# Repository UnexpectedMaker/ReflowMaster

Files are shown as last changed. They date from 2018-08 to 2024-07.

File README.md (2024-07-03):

# ReflowMaster

ReflowMaster is my original open source toaster oven reflow controller that I used to sell on tindie:
https://www.tindie.com/products/13378/

### This project is not compatible with ReflowMasterPro

Reflow Master

It's custom hardware and custom code but all open source so if you want the challenge of making one yourself or you want to hack the code, go for it!

I have a live stream build of the board here if you want to see what's involved
https://www.youtube.com/watch?v=OGQ-GZZ90oE

# ReflowMaster Design Files

Included in this repository:
- EagleCAD schematics and Board layout files (Eagle 9.1) 
- Exported Gerber files (Gerber 274X)
- STL files for the 3D printed case
- Adrduino code

# Open Source License
The hardware design files are released as open source under the CERN license. Please review the license before using these files in your own projects to understand your obligations.

# STL files for 3D printing
I have included the STL files for the case and also the exhaust fan adapter I made for my specific toaster oven. 

**NOTE:** Do not print the exhaust fan in PLA, please use PET-G or ABS as PLA warps/melts at a low temp. Also DO NOT connect the 3D printed exhaust fan directly to the metal of teh oven, it will melt and ruin your oven. You will need to add some heat resistant insulator between the metal and the 3D print. 

# Which TFT?
The TFT I am using is a 2.4" SPI TFT using the ILI9341 Driver available via...

AliExpress
https://s.click.aliexpress.com/e/_DevvrLr

Ebay
https://rover.ebay.com/rover/1/705-53470-19255-0/1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

# SAMD21 Bootloader
If you build your own Reflow Master, you will need to use a SAMD21G18 that already has an Arduino bootloader on it *before* it is put on the board. If you need to add a bootloader, you'll need an ATMEL ICE and an adapter for the chip. The cheapest adapter you can get is my SAMD21G Mangler available here...
https://www.tindie.com/products/13379/

# Updating firmware & Adding profiles - for Version 2.0.0
You can flash your Reflow Master with the Arduino IDE using the code provided above.

If you wish to add or change any of the reflow profiles, you need to do so in the code and re-flash the changes to your Reflow Master.

The Reflow Master board works like an "Adafruit Feather M0" - so you'll need to have the Adafruit Cortex m0 hardware profiles installed as well as the regular Cortex m0 Arduino profiles.

Reflow Master

You can use the instructions here to install everything you need to get up and running in the Arduino IDE:
https://learn.adafruit.com/adafruit-feather-m0-basic-proto/setup

You will also need the following libraries from Library Manager
- One Button
- Adafruit_GFX
- Adafruit_ILI9341

Once you have everything you need, you can download the code from this repo and put it into the Arduino folder where your sketches are stored, load the sketch, select Adafruit Feather M0 from the boards list, plug in your RM and turn it on, and select the correct port from the ports list and flash.
   
The easiest way to put a new profile into the code is to change one of the existing profiles, by altering the values in it's class initialiser. Information of what each value is is available in the ReflowMasterProfile.h file:
https://github.com/UnexpectedMaker/ReflowMaster/blob/master/Code/Reflow_Master_v2/ReflowMasterProfile.h
   
Enjoy!

# Support Unexpected Maker

I love designing, making and releasing my projects as open source. I do it because I believe it’s important to share knowledge and give back to the community, like many have done before me. It helps us all learn and grow.

That said, a lot of time, effort and finances have gone into designing and releasing these files, so please consider supporting me by buying some of my products:

https://unexpectedmaker.com/shop

https://www.tindie.com/stores/seonr/

Or by becoming a Patron:

https://www.patreon.com/unexpectedmaker

# Join my discord server
https://discord.com/invite/xAHpApP

# Unexpected Maker
https://unexpectedmaker.com

http://youtube.com/unexpectedmaker

http://twitter.com/unexpectedmaker

https://www.facebook.com/unexpectedmaker/

https://www.instagram.com/unexpectedmaker/

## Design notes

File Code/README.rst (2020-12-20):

Reflow Master Arduino Code
==========================

In this repository you'll find the Reflow Master code for Arduino in 2 different versions:

Reflow Master V1 and Reflow Master V2

Reflow Master V2 HISTORY:
-------------------------

- 19/12/2020 v2.00  
                    - Initial release.
- 20/12/2020 v2.01  
                    - Increased max bake time to 3 hours
                    - Added long press for Bake Time & Temp adjustment to quickly change values, clamped at max, so it won't loop
                    - Forgot to hookup minBakeTemp, minBakeTime, maxBakeTemp, maxBakeTemp variables to buttons
                    - Oven was not turned off correctly after the bake ended
- 20/12/2020 v2.02
                    - Prevent going into the bake menu when there is a TC error
                    - Set FAN to Off by default in settings
                    - Fixed some incorrect comments 
                    - Made TC error more visible on menu screen

Reflow Master V1 HISTORY:
-------------------------

- 01/08/2018 v1.0   
                    - Initial release.
- 13/08/2018 v1.01  
                    - Settings UI button now change to show SELECT or CHANGE depending on what is selected
- 27/08/2018 v1.02  
                    - Added tangents to the curve for ESP32 support, Improved graph curves, fixed some UI glitches, made end graph time value be the end profile time
- 28/08/2018 v1.03  
                    - Added some graph smoothing
- 20/05/2019 v1.04  
                    - Increased max curve to support profiles up to 8mins
                    - Added fan on time after reflow for cooldown settings
                    - Added extra profile for Ju Feng Medium temp paste
- 09/07/2019 v1.05  
                    - Fixed some bugs, Thanks Tablatronix!
- 16/09/2019 v1.06  
                    - Fixed probe offset temp not changing in settings
- 02/07/2020 v1.07  
                    - Cleaned up some Fan control and tracking code
                    - Cleaned up some debug messages
- 13/07/2020 v1.08  
                    - Fixed bug in DEBUG mode

Open Source License
-------------------

These files are released as open source under the MIT license. Please review the license before using these files in your own projects to understand your obligations.

Support Unexpected Maker
------------------------

I love designing, making and releasing our projects as open source. I do it because I believe it’s important to share knowledge and give back to the community, like many have done before me. It helps us all learn and grow.

That said, a lot of time, effort and finances have gone into designing and releasing these files, so please consider supporting me and following me on social media

If you'd like to support me on my journey, please consider buying one of my products on tindie

https://www.tindie.com/stores/seonr/

or at
https://unexpectedmaker.com/shop

Or become a Patron:

https://www.patreon.com/unexpectedmaker

Unexpected Maker
===================
http://youtube.com/c/unexpectedmaker

http://twitter.com/unexpectedmaker

https://www.facebook.com/unexpectedmaker/

https://www.instagram.com/unexpectedmaker/

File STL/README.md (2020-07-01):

# ReflowMaster 3D files for the Case

Reflow Master is my open source toaster oven reflow controller that I also sell full assembled on tindie:
https://www.tindie.com/products/13378/

Reflow Master

It's custom hardware and custom code but all open source so if you want the challenge of making one yourself or you want to hack the code, go for it!

I have a live stream build of the board here if you want to see what's involved
https://www.youtube.com/watch?v=OGQ-GZZ90oE

# STL files for 3D printing

Included in this folder are 3 versions of the Reflow Master case.

Functionally, the Rev1 and Rev2 are the same, but the Rev2 has a nicer, more modern look, and locations for the power switch and nuts for the screws print better.

There is also a Rev2 5.08mm version of the case that is bigger than the other Rev2, and that is because I am now shipping the latest version of my Reflow Master with 5.08m screw terminals, which requires extra space inside to fit.

**NOTE:** Do not print the exhaust fan in PLA, please use PET-G or ABS as PLA warps/melts at a low temp. Also DO NOT connect the 3D printed exhaust fan directly to the metal of teh oven, it will melt and ruin your oven. You will need to add some heat resistant insulator between the metal and the 3D print. 

Enjoy!

# Back me on Patreon?
I love making and designing projects but sharing open source projects takes a lot of thought and time. I do it because I think it’s important to share knowledge and give back to the community like many have done before me.

If you find this project useful or want to see more open source projects like it, please consider backing me on Patreon to say thanks!



Or by buying one of my products on tindie:

https://www.tindie.com/stores/seonr/

Or by buying one of my TinyPICO products:

https://tinypico.com

# Unexpected Maker
http://youtube.com/c/unexpectedmaker

http://twitter.com/unexpectedmaker

https://www.facebook.com/unexpectedmaker/

https://www.instagram.com/unexpectedmaker/

https://www.tindie.com/stores/seonr/

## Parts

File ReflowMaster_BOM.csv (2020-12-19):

Qty | Value | Device | Package | Parts | Description | PROD_ID | SF_SKU | VALUE
1 |  | ATSAMD21G-A | TQFP-48 | SAMD21 | Atmel SAMD21G SMART ARM-Based Microcontroller | IC-13064
5 |  | HEADER | 1X02 | BUZZ, FAN, K-TYPE, RELAY, SWITCH | 0.1” Header
1 |  | HEADER | 1X04_NO_SILK | J1 | 0.1” Header | CONN-09696
1 |  | HEADER | 1X14_NO_SILK | TFT | 0.1” Header
1 |  | USB-B-MICRO-SMD | USB-B-MICRO-SMD | J2 | USB Type Micro-B Connector | CONN-11752
2 | 0.1uF | CAPACITOR | 0805 | C3, C7 | Ceramic Capacitors
1 | 100k | RESISTOR | 0805 | R1 | RESISTOR
4 | 10k | RESISTOR | 0805 | R4, R5, R6, R11 | RESISTOR
1 | 10nF | CAPACITOR | 0805 | C5 | Ceramic Capacitors
2 | 10uF | CAPACITOR | 0805 | C6, C8 | Ceramic Capacitors
2 | 12pF | CAPACITOR | 0805 | C2, C4 | Ceramic Capacitors
1 | 1K2 | RESISTOR | 0805 | R9 | RESISTOR
2 | 1uF | CAPACITOR | 0805 | C1, C14 | Ceramic Capacitors
2 | 2K | RESISTOR | 0805 | R3, R8 | RESISTOR
1 | 300R | RESISTOR | 0805 | R7 | RESISTOR
1 | 32.768 | XTAL-3.2X1.5 | XTAL3215 | X2 | SMT Crsytal
1 | 430k | RESISTOR | 0805 | R2 | RESISTOR
1 | 600mA/40V | TRANS_NPN-MMBT2222AL | SOT23-3 | Q1 | NPN transistor | TRANS-08049 |  | 600mA/40V
1 | AP2112K | VREG_SOT23-5 | SOT23-5 | LDO | SOT23-5 Fixed Voltage Regulators
1 | GENERIC-SOIC8 | GENERIC-SOIC8 | SO08-UNIVERSAL | MAX31855 | Generic narrow & wide SOIC8
1 | GR | LED | 0805 | 13 | LED
1 | MBR120 | DIODESOD-123 | SOD-123 | D1 | Diode
4 | SWITCH-SPST | SWITCH-SPST | TACTILE_SWITCH_PTH_RIGHT_ANGLE_KIT | B1, B2, B3, B4 | Momentary Switch (Pushbutton) - SPST | CONN-10672 | COM-10791
1 | RD | LED | 0805 | 1 | LED
1 | SPST_TACT-KMR2 | SPST_TACT-KMR2 | KMR2 | SW1 | SMT 6mm switch, EVQQ2 series
1 | YEL | LED | 0805 | 2 | LED

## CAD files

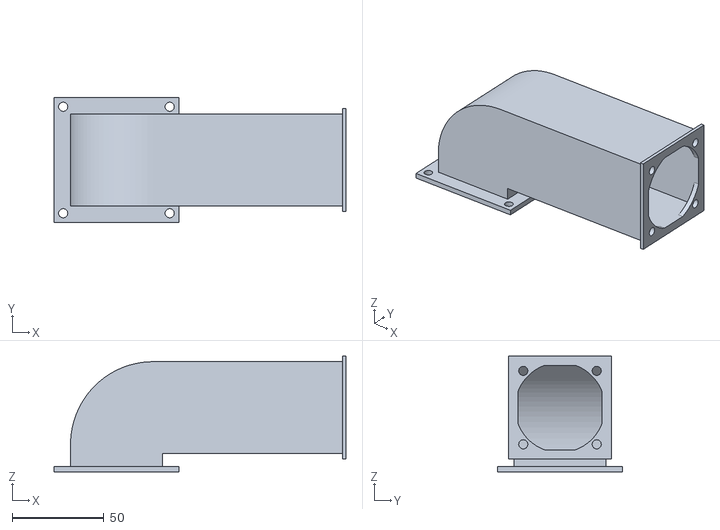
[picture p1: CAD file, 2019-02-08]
STL/Fan_Exhaust.stl
159.0 x 68.0 x 63.0

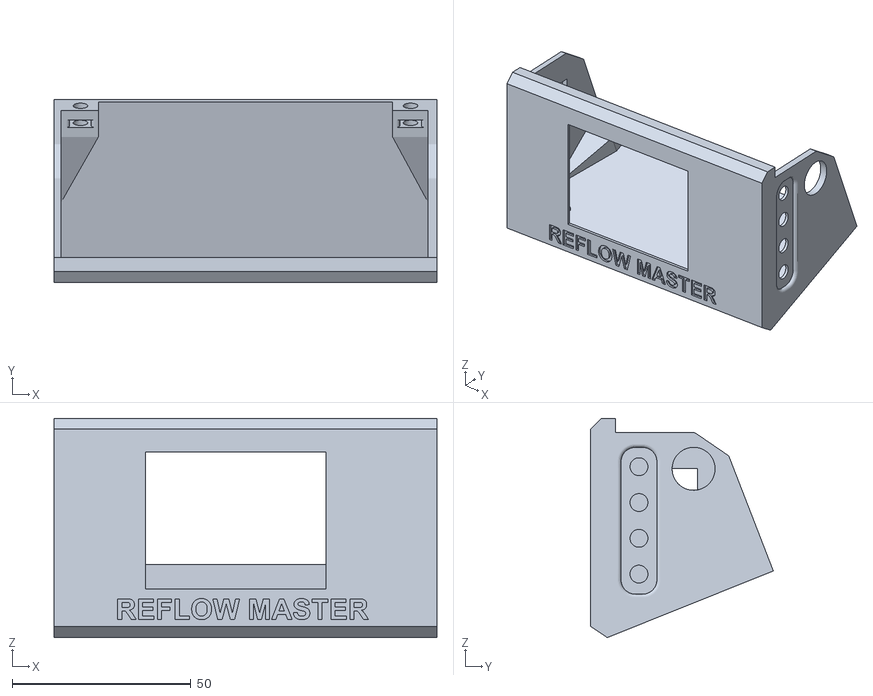
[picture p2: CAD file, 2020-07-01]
STL/Rev2 Case 2.54mm Screw Terminals/Reflow_Master_Front_V2.stl
107.0 x 51.0 x 61.2

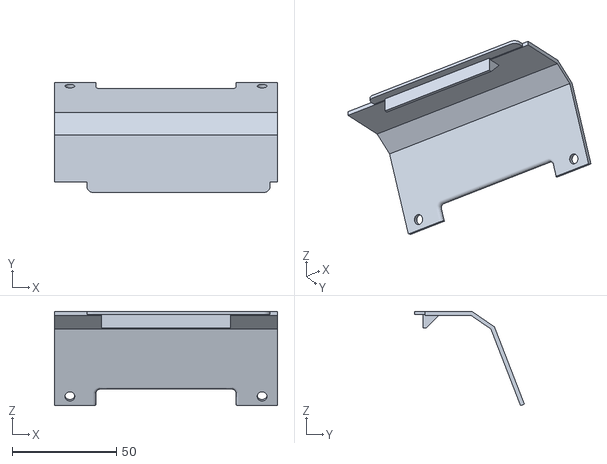
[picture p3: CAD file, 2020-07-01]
STL/Rev2 Case 5.08mm Screw Terminals/Reflow_Master_Back_V2_508mm.stl
107.0 x 52.7 x 45.3

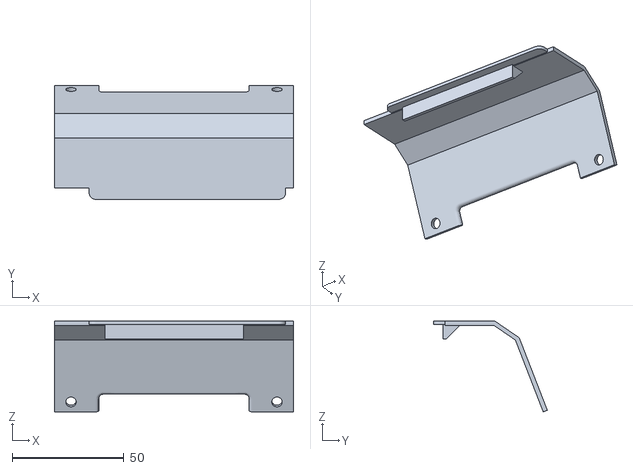
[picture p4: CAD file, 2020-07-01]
STL/Rev2 Case 2.54mm Screw Terminals/Reflow_Master_Back_V2.stl
107.0 x 50.9 x 40.6

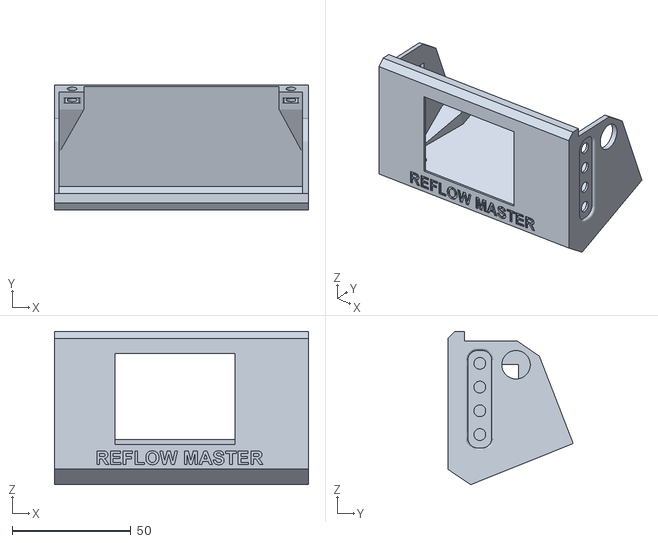
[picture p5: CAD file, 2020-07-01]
STL/Rev2 Case 5.08mm Screw Terminals/Reflow_Master_Front_V2_508mm.stl
107.0 x 52.8 x 64.6

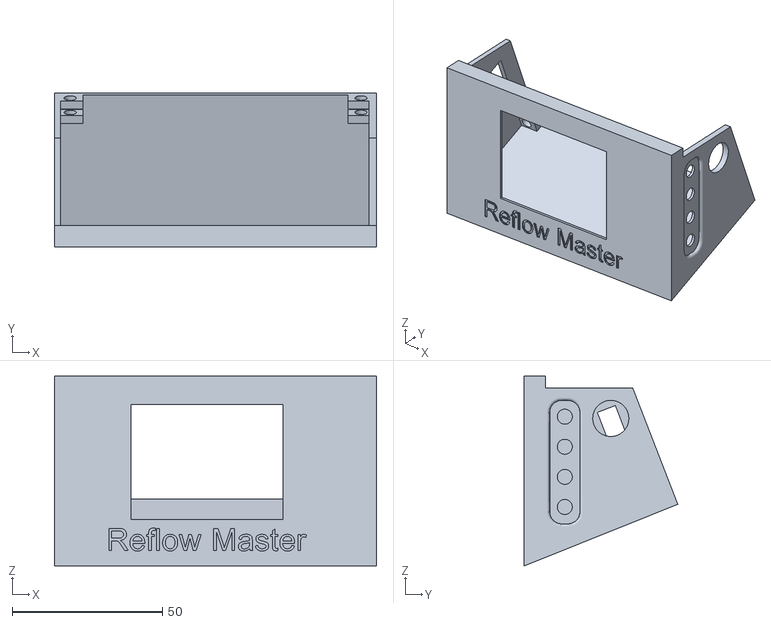
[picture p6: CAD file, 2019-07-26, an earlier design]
STL/Rev1 Case 2.54mm Screw Terminals/Case_Front_8.5mm_Header.stl
107.0 x 51.0 x 63.1

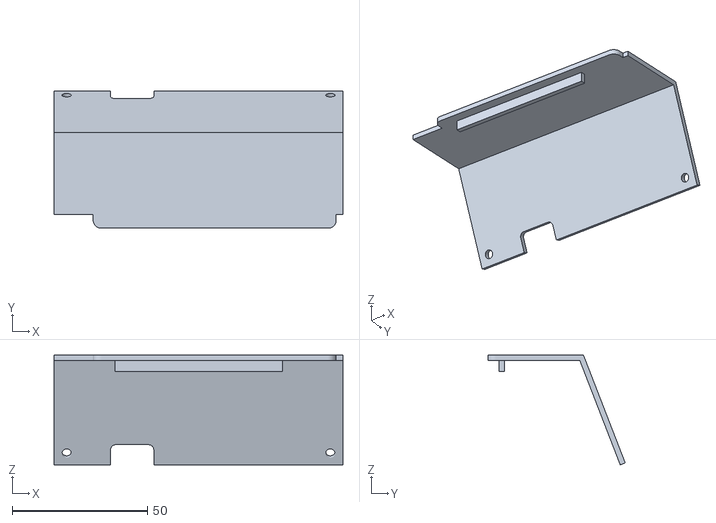
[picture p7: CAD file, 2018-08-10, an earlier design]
STL/Rev1 Case 2.54mm Screw Terminals/Case_Back.stl
107.0 x 50.9 x 40.6

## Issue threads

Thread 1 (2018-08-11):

BOM and Schematic PDF

DirtyEngineer, 2018-08-11:
Great project. Thanks for sharing it!

Might I suggest listing a BOM of the purchased parts?

 Affiliate links are always welcome as well.

Also I support your decision to add a "Buy Me A Coffee" link. So many times I've found and used an open source project and have no way of expressing my thanks to the person that put all the hard work into it.  I really wish GitHub had this integrated.

I've attached a PDF of the current schematic (Rev F) as I find this super handy when checking out a project.

[ReflowMaster_Rev_F.pdf](https://github.com/UnexpectedMaker/ReflowMaster/files/2280601/ReflowMaster_Rev_F.pdf)

UnexpectedMaker, 2018-08-11:
Hey Jon,

That’s quite funny… I had a schematic PDF and a BOM txt file sitting in my local repo uncommitted - had totally forgotten to push it… I am glad I did forget though, the BOM was slightly out of date and still included the SWD Debug header that is no longer on the board.

Thanks for the reminder to push it :-)

I’m not a fan of using a BOM that is linked to a supplier as everyone gets their parts from different places, and I often will source a set of parts for a board from 3-4 places based on costs and availability of parts, so I’m just including a TXT based BOM that people can load into their preferred suppliers sites.

I agree that GITHUB should offer a built in “donate” option for free repos, but it wasn’t too much effort to get this setup - no takers yet though ;)

Keep fighting the good fight!

DirtyEngineer, 2018-08-12:
Any chance you could include a little more detail as to specifically what screen is needed to work with this?

You would have had takers for your "donate" link if you hadn't threaten to refund donations during your live stream :)

UnexpectedMaker, 2018-08-12:
I've added links for AliExpress and eBay in the readme, and also added a bit about needing to install a bootloader on the SAMD21G before putting it on the board.

The people that were going to donate on my stream already support me by buying my products on tindie.. the donate button is for people that are not buying my products, but are instead using my open source files to make their own ;)

Closed 2018-08-11.

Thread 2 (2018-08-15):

hermite tangents not supplied

tablatronix, 2018-08-15:
I am surprised your environment doesn't crash because of this, esp32 does

```C++
  baseCurve.setPoints(CurrentGraph().reflowGraphX, CurrentGraph().reflowGraphY, CurrentGraph().len);
  baseCurve.setDegree( Hermite );
```

You specify Hermite, but provide no tangents to _m
`void setPoints( float x[], float y[], float m[], int numPoints );`

in spline, this causes exceptions on esp32, loadprohibited , since _m is unset

```C++
     // calc()
     // _m[i], _m[i+1]
      return hermite( ((x-_x[i]) / (_x[i+1]-_x[i])), _y[i], _y[i+1], _m[i], _m[i+1], _x[i], _x[i+1] );
```

Oddly , The spline lib doesn't seem to catch this or ensure that _m is set for hermite sets..

No idea what memory this accesses on samd, maybe its safer, shrug.

tablatronix, 2018-08-15:
my workaround is to just add tangents array to the reflowGraph class
and  fill it with 0s

```C++
float tangents[10];
...
for ( int i = 0; i < minLength; i++ )
tangents[i]     = 0;
```

UnexpectedMaker, 2018-08-15:
Hmm, interesting that it doesn't crash on the SAMD... I'll update the codebase anyway to include a defualt set of tangents. Thanks!

Closed 2018-08-15.

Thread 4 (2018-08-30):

SSR PWM potentially not fully on when set at 255

HowManyOliversAreThere, 2018-08-30:
According to the [Adafruit guide on Arduino sketches on SAMD21](https://learn.adafruit.com/adafruit-feather-m0-basic-proto/adapting-sketches-to-m0#analogwrite-pwm-range-7-7), performing an `AnalogWrite(255)` only sets the PWM to 255/256 rather than 255/255. As such, a special case is required to handle when it's at 255 and just digitally set the pin high. This is relevant to the `SetRelayFrequency` function

Might be worth investigating this, as it will improve ramp-up (marginally) and stop the toaster getting cut off and then slammed on again in periods where it should just be happily humming away. Unfortunately I don't have any hardware with which I could test this sorry, so might be a red herring if the info is wrong or the SAMD21 Arduino core has been changed.

UnexpectedMaker, 2018-09-01:
Hey Oliver
Thanks for this info. When I get some time I can hook a RM up to my scope and check out the results, but it's a simple thing to just add some code to do a digitalWrite(HIGH) and then PWM should be 100% duty cycle, though I assume it's not going to make any measurable change in oven temp/speed.
Seon

Closed 2020-12-21.

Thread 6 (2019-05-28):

Bom don’t contain certain part names only what package

NoSkillsToPayTheBillz, 2019-05-28:
I can’t seen to figure out what voltage regulators you are using? The diode is also just the package type. Also the crystal is the same just the package. Kinda confused about the 12.5 pf 0805s also since they aren’t able to be bought. I’ve asked and searched a few suppliers and have been told such a part isn’t made.

UnexpectedMaker, 2019-05-28:
I just updated the repo with missing component names and changed 12.5pF caps for the XTAL to 12pF.
Cheers :-)

NoSkillsToPayTheBillz, 2019-05-28:
Thanks that makes it some much easier only thing is what crystal is it that your using

UnexpectedMaker, 2019-05-28:
The Crystal I am using is discontinued, so you'l need to just source a 32.768 crystal with the size specs from the BOM and use that with matching caps. There are stacks to choose from.,

NoSkillsToPayTheBillz, 2019-05-28:
I ordered a NX3215SA so that should work match’s your specs. Thanks for your time I know your super busy with the Pico crowd source.

NoSkillsToPayTheBillz, 2019-05-28:
I ordered a NX3215SA so that should work match’s your specs. Thanks for your time I know your super busy with the Pico crowd source.

Closed 2019-05-28.

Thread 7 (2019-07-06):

abort immediate

tablatronix, 2019-07-06:
abort does not turn off heater immediately

- [ ] add `SetRelayFrequency(0);`
do not wait for return and loop

```C++
void AbortReflow()
{
   SetRelayFrequency(0); // relay off
  if ( state == 1 || state == 2 || state == 16 ) // if we are in warmup or reflow states
  {
```

- [x] moved in front of state checking, and always abort!, in case a bug causes a bad state etc.

UnexpectedMaker, 2019-07-07:
This has been improved in v1.04 that I am going to upload today, but the abort button should never be able to be pressed outside of those states, so not sure why you need SetRelayFrequency(0); outside the if statement.

It is inside the if statement in v1.04 :-)

tablatronix, 2019-07-07:
It was a safety thing, in case of a bug or loss of state , abort aborts always

UnexpectedMaker, 2019-07-07:
Right, but again, AbortReflow() is only ever called from a button press, and that press can only happen in those states...

```
    else if ( state == 1 || state == 2 || state == 16 )
    {
      AbortReflow();
    }
```

tablatronix, 2019-07-07:
I am always thinking about future abstraction less code coverage if abort gets called from a big red button or tc failure

Closed 2020-12-21.

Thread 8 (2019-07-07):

BUG? startFullBlast

tablatronix, 2019-07-07:
If I set startFullBlast true, ( I expected startup to be 100% for a bit )

Instead it goes 100% and stays 100%

I can't see whats wrong here

```C++
  // override for full blast at start
if ( set.startFullBlast && timeX < CurrentGraph().reflowGraphX[1] )
    duty = 256;`
```

seems like it should only override the first graph point or reflow level but it keeps going

Anyone have ideas, I am still trying to understand the `MatchTemp` function and timex graphing loop

UnexpectedMaker, 2019-07-07:
Hey mate - it sits at 100% for the entire start ramp, until it gets to the start of the pre-soak (reflowGraphX[1]) - this is really only designed for either high temp pastes to ensure you get to pre-soak as soon as it can, or for ovens that are just not powerful enough to get to any pre-soak in time.

I don't think anyone should be trying to use high temp paste in a toaster oven - bad bad bad!

It's pretty dangerous as it can overshoot the pre-soak start temp by a bit on a bad oven that can change temp fast enough.

tablatronix, 2019-07-07:
Hey thanks!
Yeah that is what I thought the code would do,

But it seems to do something else straight up

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

UnexpectedMaker, 2019-07-07:
Oh, you are getting past the wanted temp before pre-soak, and starting above start value - interesting. will fix that now in 1.0.4 - thanks for the use case - never encountered it before myself!

tablatronix, 2019-07-07:
I figured it was something like that, I have been working on some enhancements to pr and was always having an issue when I start with oven warmer than the profile start temp, I assume I need to do something to catch up the indexes to each other or something.

timeX seems to lag behind where it should be and is not synched to actual start temp, still reading the reflow code, I have almost all the rest figured out

UnexpectedMaker, 2019-07-07:
> timeX seems to lag behind where it should be and is not synched to actual start temp, still reading the reflow code, I have almost all the rest figured out

timeX doesn't lag behind, the system is designed to look ahead. it's never changing temp based on what it needs at it's current time... but at a look ahead time, as toaster ovens cant change temp that fast.

tablatronix, 2019-07-07:
Is timex an index of time? Of reflow slots 0-x?

UnexpectedMaker, 2019-07-07:
timeX is used to index into the curve of the current reflow graph, where CurrentGraph().reflowGraphX is time and CurrentGraph().reflowGraphY is temp. It's also the time count in seconds.

```
    if ( timeX < CurrentGraph().reflowGraphX[2] )
      wantedTemp = CurrentGraph().wantedCurve[ (int)timeX + set.lookAheadWarm ];
    else
      wantedTemp = CurrentGraph().wantedCurve[ (int)timeX + set.lookAhead ];
```
CurrentGraph().wantedCurve is an array of temps for every second of the profile, that is pre-processed when the profile is loaded on start or when the profile is changed.

tablatronix, 2019-07-07:
new code seems to work, I must misunderstand it, thanks

This is what threw me, timex was way greater and it was still doing full duty
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

tablatronix, 2019-07-07:
W00t

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

UnexpectedMaker, 2019-07-07:
Wicked! I have some thoughts on how to improve the visual look of the profile graph - but not had time to implement yet - I hate the smooth tangents on it right now, but messing with the tangent values isn't doing what I expect, so going to write my own curve code ;) one day....

UnexpectedMaker, 2019-07-07:
Is that running in your ESP32 port? or on SAMD?

tablatronix, 2019-07-07:
esp8266

UnexpectedMaker, 2019-07-07:
Wow, that's messy and marginally dangerous! ;)
I just pushed v1.05 - have fun!

Closed 2020-12-21.

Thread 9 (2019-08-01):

BUG? overshoots

tablatronix, 2019-08-01:
I think I found a bug, but I am hacking on my own fork and have not reproduced using upstream so was wondering if someone could confirm.

I noticed when I had sharp curves ( I am making some custom curves ) I was getting massive overshoots, 20-30C, and the heater would turn on randomly when way above wanted temp and even on cooldown, so I figured something might be wrong.

It looks like percent can be negative which causes duty to go above 0% and pulses the heater when it is not needed.

I added some sanity checking for perc and it seems to made a huge difference.
But if someone could check and test and make sure this is not going to break something.
change is below

`MatchTemp()`
```C++
    // prevent perc less than 1 and negative and greater than 100
    perc = constrain(wantedDiff - tempDiff,0,100);
    if(perc < 1) perc = 0;
```

**BAD log**
(ignore the T stamp, I am using a holding pattern)
```PHP
T: 70.00  Current: 125.30  Wanted: 105.00  T Diff: 0.00  W Diff: 0.00  Perc: 0.00  Delta: -20.30  Base: 0.00 -> SetRelayFrequency
RELAY Duty Cycle: write: 0.00 0.00% Using Power: 100%
Holding..

T: 70.00  Current: 125.68  Wanted: 105.00  T Diff: 0.37  W Diff: 0.00  Perc: 0.00  Delta: -20.68  Base: 0.00 -> SetRelayFrequency
RELAY Duty Cycle: write: 0.00 0.00% Using Power: 100%
Holding..

T: 70.00  Current: 125.60  Wanted: 105.00  T Diff: -0.08  W Diff: 0.00  Perc: 0.08  Delta: -20.60  Base: 0.00 -> SetRelayFrequency
RELAY Duty Cycle: write: 12.00 4.69% Using Power: 100% <------- HMMMM
Holding..

T: 70.00  Current: 125.39  Wanted: 105.00  T Diff: -0.21  W Diff: 0.00  Perc: 0.21  Delta: -20.39  Base: 0.00 -> SetRelayFrequency
RELAY Duty Cycle: write: 36.00 14.06% Using Power: 100%
```

tablatronix, 2019-08-01:
hmm, looks like there is something else going on actually.

disregard until I can look a bit more

```PHP
T: 70.00  Current: 131.70  Wanted: 105.00  T Diff: -0.37  W Diff: 0.00  Perc: 0.00  Delta: -26.70  Base: 0.00 -> SetRelayFrequency
RELAY Duty Cycle: write: 0.00 0.00% Using Power: 100%
Holding..
T: 70.00  Current: 130.65  Wanted: 105.00  T Diff: -1.05  W Diff: 0.00  Perc: 1.05  Delta: -25.65  Base: 0.00 -> SetRelayFrequency
RELAY Duty Cycle: write: 180.00 70.31% Using Power: 100%
Holding..

T: 70.00  Current: 130.85  Wanted: 105.00  T Diff: 0.20  W Diff: 0.00  Perc: 0.00  Delta: -25.85  Base: 0.00 -> SetRelayFrequency
RELAY Duty Cycle: write: 0.00 0.00% Using Power: 100%
Holding..
```

tablatronix, 2019-08-01:
I was able to deal with my overshoots by increasing lookaheadwarm and bumping power up a few thenths.

No idea what the pulsing the oven when its over wantedtemp is, something with the currentDetla (<mispelling) but I am not sure what that code does yet or what the variables you chose are

I am assuming some kind of swing 5, 15 and 172 and base 32, 128
Might look again later and see what the math is doing.

tablatronix, 2019-08-02:
I think alot of these issues are precision issues that do not present on the samd21, I am waiting to get one to be able to PR against master without breaking stuff or fighting other bugs.

Seems everything is a float and does not need to be, there are also alot of comparison warnings with -wall so might be any of those , I also have better luck sometimes by disabling lookahead, maybe it your oven is fast enough it harms more than helps

Closed 2020-12-21.

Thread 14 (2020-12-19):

Differential controller performance

DurandA, 2020-12-19:
Hi @UnexpectedMaker and thanks for your open-source projects and YouTube videos.

I am making a pretty similar project for a [hot plate](https://aliexpress.com/item/32888343657.html) where I replace the original controller board with a custom one. Since there is just space for a segment display and some buttons, reflow profile will be configured from a smartphone using BLE. The [hardware](https://easyeda.com/DurandA/reflow) is mostly final and I am now working on the [firmware](https://github.com/DurandA/reflow946) using ESP-IDF.

I stumbled upon your project and found that you use the same thermocouple chip (MAX31855) than me and I am wondering how did you settle on the current temperature controller. I started working on a PID controller but saw that that you are only using a differential input:
https://github.com/UnexpectedMaker/ReflowMaster/blob/29f8a3fb8e1a09a3da2df962912d4bd50d375017/Code/Reflow_Master_v2/Reflow_Master_v2.ino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

I did not try to tune the PID controller on the plate yet but was wondering how did you settle on a differential-only controller? Does the temperature closely match the chosen profile? I also saw some recommendations to rather use bang-bang (on-off) controllers for heaters due to the large inertia.

UnexpectedMaker, 2020-12-21:
I don't think PID is a good fit for reflow, so I implemented my own solution. It's not really differential control, and more a combo of a few techniques, that allows users to tune in a more understandable way.
But this really isn't a RM issue, so maybe my discord server is a better place to talk about it 👍
https://discord.com/invite/xAHpApP

DurandA, 2020-12-21:
Whoops, I meant proportional controller.

Sorry for opening an issue and thanks for the Discord link!

Closed 2020-12-21.

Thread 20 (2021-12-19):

Shortage of ATSAMD21G-A?

Bazmundi, 2021-12-19:
Currently looks like ATSAMD21G-A are hard to source.   How many of the SAM D21 family might be an optional drop-in replacement please?  Based on, I guess, why you opted for that chip.

https://au.mouser.com/c/?q=ATSAMD21G seem to have various SAM D21G variants.

UnexpectedMaker, 2021-12-19:
Reflow Master only supports the ATSAMD21G18A - in the QFP package.

Anything else will require you to modify the PCB design (if you go for a QFN package of the 21G18A) or require bootloader and code changes to work on a version with less Flash/SRAM.

UnexpectedMaker, 2021-12-19:
It's in stock at mouser... though not many.
https://au.mouser.com/ProductDetail/Microchip-Technology-Atmel/ATSAMD21G18A-AUT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

You only need 1 right?

Bazmundi, 2021-12-19:
Ta, I'll get me 10 but missed that in the search - too literal.

On Sun, Dec 19, 2021 at 5:39 PM Unexpected Maker ***@***.***>
wrote:

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

Bazmundi, 2021-12-19:
DOH, can't get the K-type  MAX31855K, have to wait (apparently)

On Sun, Dec 19, 2021 at 7:06 PM Asterion Daedalus <
***@***.***> wrote:

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

andygrillo, 2022-03-27:
ATSAMD21G18A in QFP seems to be hard to find with the main distributers. Given that I only need 1 for this project, and I don't have a programmer to load arduino, I thought to buy this board from aliexpress:

https://www.aliexpress.com/item/1005003445206496.html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

It appears from the fuzzy photo to have the ATSAMD21G18A in QFP package, and I can erasily upload the bootloader using the board. Once done I can hot gun the chip off the board and use it for the reflow oven PCB.

What do you think?

UnexpectedMaker, 2022-03-27:
Sure, using a doner chip from another board is fine, so long as you have the tools and skills to remove it and re-solder without killing it.

andygrillo, 2022-03-27:
great, ill do that then. I would assume a hot air gun should do the trick.

Closed 2023-03-29.

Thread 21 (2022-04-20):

Updated Board Files?

dmadison, 2022-04-20:
I ordered a board from you last year (thank you, by the way!) and it's labeled "2020-2". It looks like the EAGLE files in the repo are labeled "2018-3" and are missing the programing header.

Is there any chance you could update the board files in the repo to the latest version?

UnexpectedMaker, 2022-04-20:
Hi David, the files I'm keeping full open source are the original design files.
Is there a reason you need the newer files?

dmadison, 2022-04-20:
Thanks for the quick response, Seon.

I'm working on putting the controller, relay, and everything else into its own fully contained enclosure. As part of that I was planning to build an add-on button board so that the buttons face the same direction as the screen. I was hoping to use the design files as a position and wiring reference.

UnexpectedMaker, 2022-04-20:
The buttons are the same from a wiring point of view. Boards are identical in functionality and still run the same code. Spacing on buttons etc are also still the same. The board grew in the other direction just a little, so you should be able to reference the online version here for what you want to do.

dmadison, 2022-04-20:
Oh, I didn't realize it had grown in size as well. I'm planning on building a mounting bracket for the LCD / controller sandwich, so that might have an effect.

I don't want to make more work for you, but would you consider sharing a vector model of the board (DXF/SVG) with just the edge outline and drill points? That would be all I need for a CAD reference.

UnexpectedMaker, 2022-04-20:
This is the best I can do atm:
[ReflowMaster_Outline.pdf](https://github.com/UnexpectedMaker/ReflowMaster/files/8518353/ReflowMaster_Outline.pdf)

If you cant get what you need from this, I can look at something else on the weekend.

dmadison, 2022-04-20:
I can definitely make that work. Thanks!

dmadison, 2022-04-21:
In case it helps anyone, here's a cleaned up SVG version of the above file. I removed the vias and made the holes accurate to size (more or less):

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

Closed 2022-04-20.

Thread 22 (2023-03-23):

Which USB socket?

pastaclub, 2023-03-23:
Some BOM items are hard to identify, especially the Micro USB socket. What is the exact component used?

I tried two different components but they do not exactly fit the footprint. I noticed the two holes in the PCB, presumably for little bolts in the component (which would actually be very useful for manual pick and place).

Also, which exact MCU is used? The BOM just says ATSAMD21G-A, but there are dozens of variations of that chip in a 48pin package. Does it matter or can I pick any?

ns2gupta, 2023-03-29:
I think the design changed a lot since it was posted. I see that the new version uses ESP32.

@UnexpectedMaker, can you please share the updated schematic and board layout?

UnexpectedMaker, 2023-03-29:
> I think the design changed a lot since it was posted. I see that the new version uses ESP32.
>
> @UnexpectedMaker, can you please share the updated schematic and board layout?

Reflow Master hasn't changed design.

The ESP32 version is Reflow Master Pro, a different product and not open source.

UnexpectedMaker, 2023-03-29:
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

SAMD21G18A is the version you need. The specific USB connector is no longer available, nor can I find it listed, so you'll need to source a matching one, or alter the PCB to use a different connector and get the boards re-made.

pastaclub, 2023-04-01:
Thank you for the support!

Closed 2023-04-01.

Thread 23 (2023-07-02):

Ali Express Link is broken

laenzlinger, 2023-07-02:
Unfortunately the Link for buying the TFT on Ali Express is broken: AliExpress http://s.click.aliexpress.com/e/bQYyZYRe

Mike-Menci, 2023-07-02:
use any that has; /Google/  TFT display 2.4" SPI TFT using the ILI9341
or for example :
like this one :
https://www.amazon.de/-/en/HiLetgo-ILI9341-Display-Touch-Arduino/dp/B0814LK18M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

On Sun, 2 Jul 2023 at 21:45, Christof Laenzlinger ***@***.***>
wrote:

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

--
Mike

"--

**************************************************************************************************************
*This e-mail may be confidential and it may also be legally privileged. If
you are not the addressee you may not copy, forward, disclose or use any
part of it. If you have received this message in error, please delete it
and all copies from your system and notify the sender immediately by return
e-mail. Internet communications cannot be guaranteed to be timely, secure,
error or virus-free. The sender does not accept liability for any errors or
omissions. *
* SAVE THE NATURE - SAVE PAPER - THINK BEFORE YOU PRINT!  *"

Closed 2024-01-13.

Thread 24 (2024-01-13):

Reflow Master Pro ESP32 Code ¿?

jlabordaversa, 2024-01-13:
It is Reflow Master Pro ESP32 code available open source? I wanted to add some improvements to my oven.

Mike-Menci, 2024-01-13:
Yes Go ahead!

UnexpectedMaker, 2024-01-13:
No, reflow Master Pro is not open source.

UnexpectedMaker, 2024-01-13:
> It is Reflow Master Pro ESP32 code available open source? I wanted to add some improvements to my oven.

What functionality did you want added?

jaimelaborda, 2024-01-14:
Thank you very much for your reply.

I wanted to add PWM for fan outputs and also ideally I wanted to be able to turn the graphical interface 90 degrees so I can use it vertically as it would better fit my toaster oven. I am also thinking about changing the display to an smaller one.
But of course, if the project is not open source I cannot. I hoped that if the first version was open source this second one with the ESP32 would also be open source.

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

UnexpectedMaker, 2024-01-14:
@jaimelaborda AUX output is already PWM - You have the ability to set the FREQ and the % is the duty cycle.

If you can source a 2.2" ILI9341 screen that's 320x240, you can just switch the screens out, but that's not much smaller. Going smaller also drops the resolution and that's not compatible with the firmware.

Screen rotation or alternate resolution is not possible as the code is written fixed for 320x240 in the specific orientation the RMP ships in.

Closed 2025-01-08.

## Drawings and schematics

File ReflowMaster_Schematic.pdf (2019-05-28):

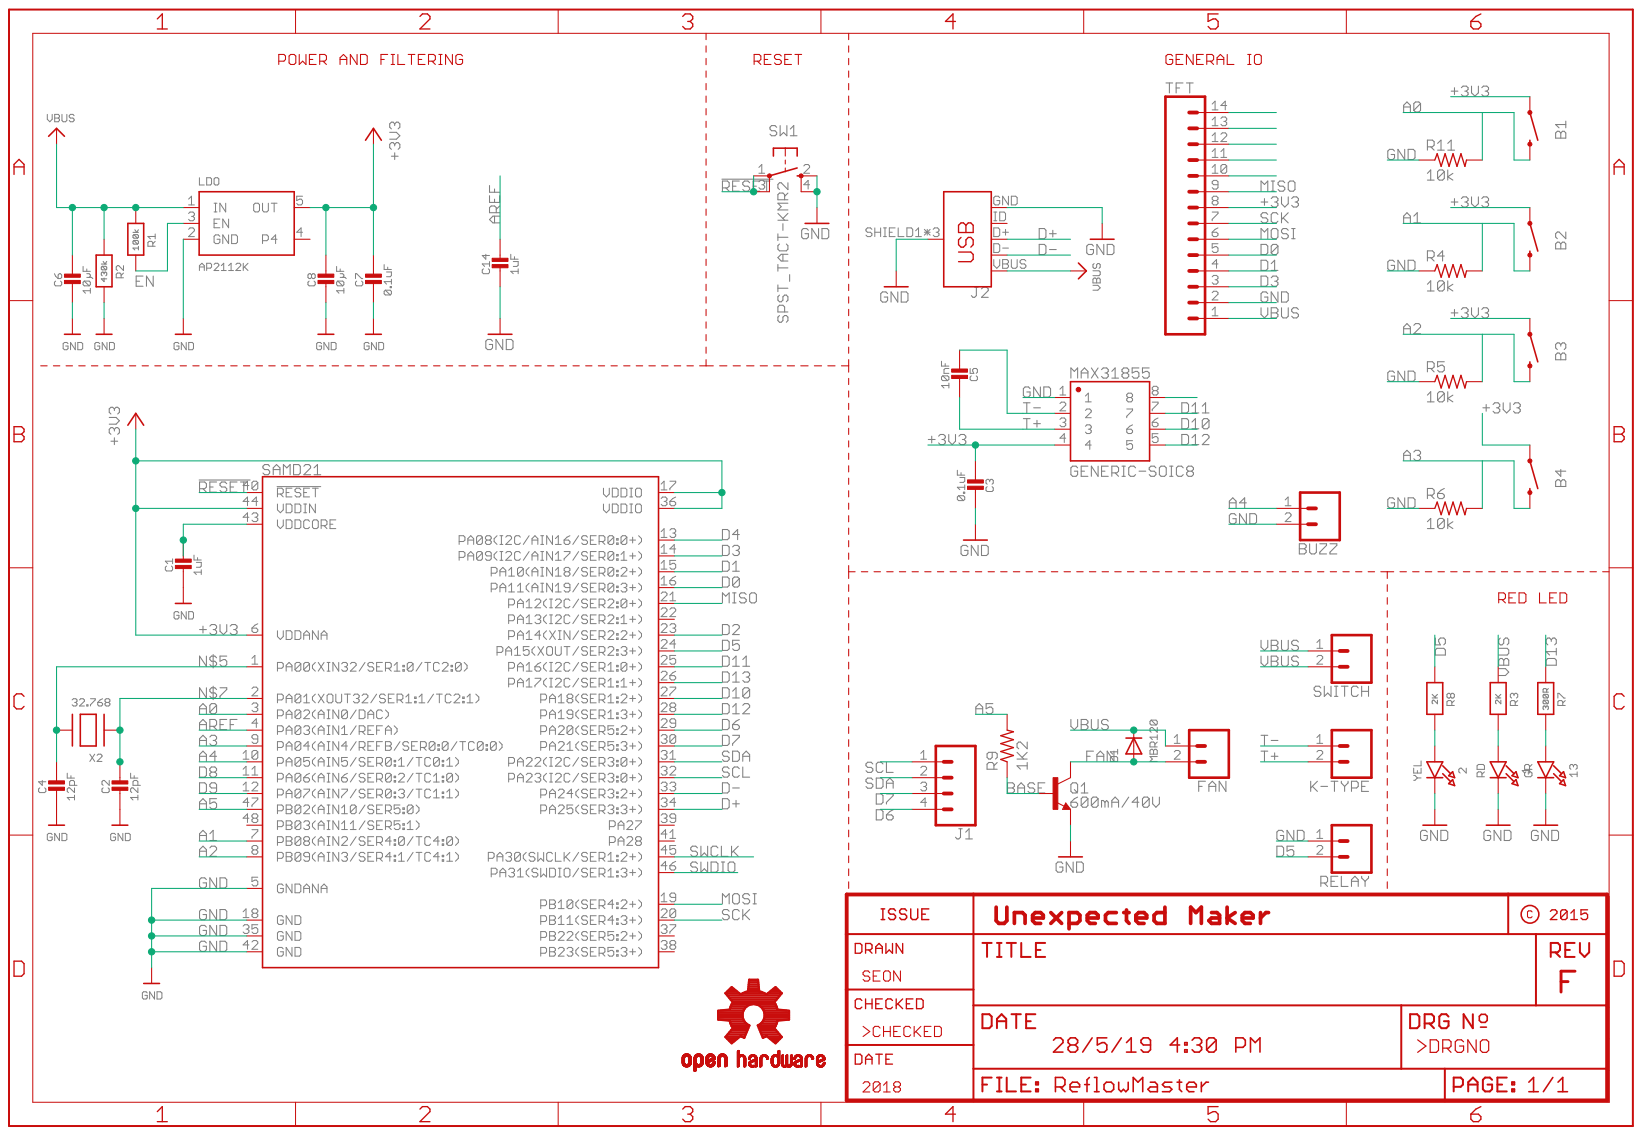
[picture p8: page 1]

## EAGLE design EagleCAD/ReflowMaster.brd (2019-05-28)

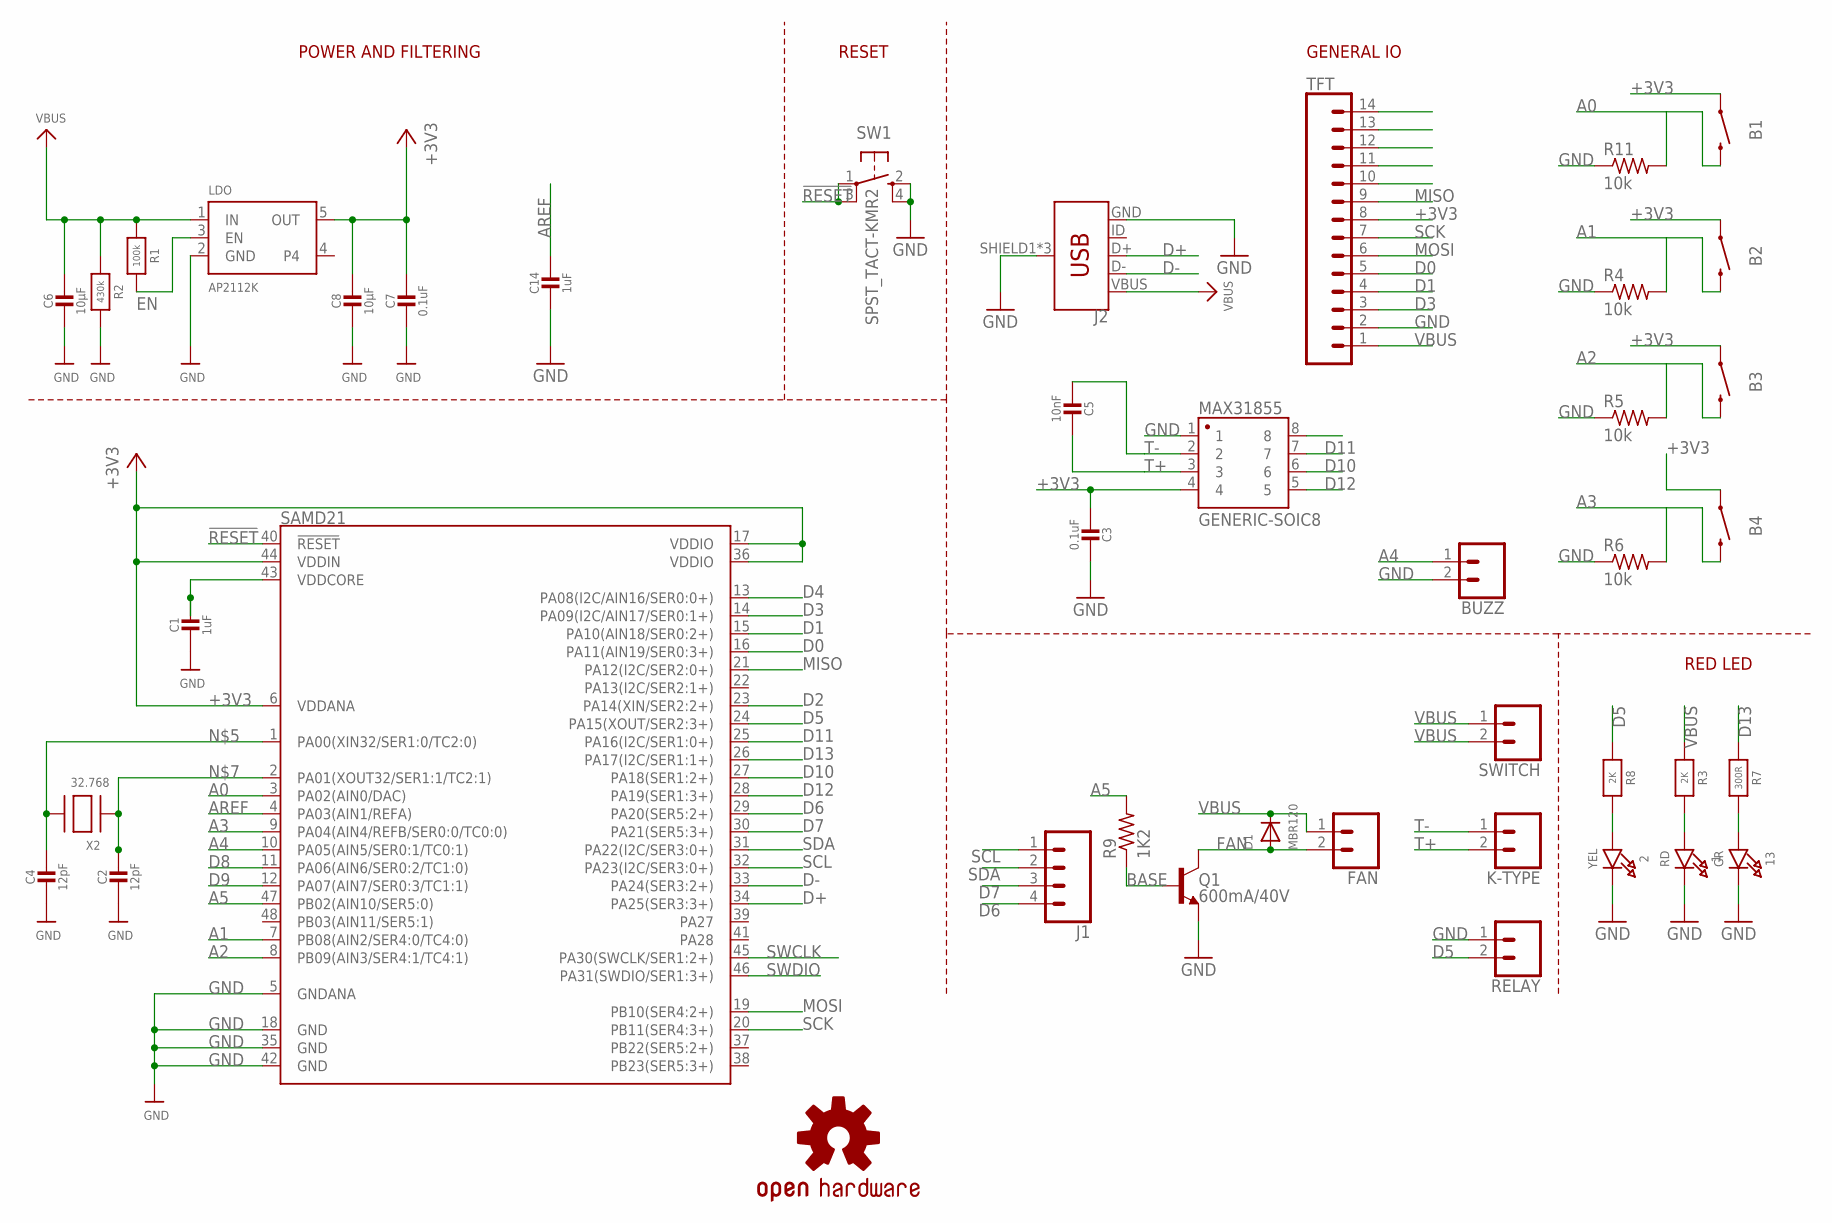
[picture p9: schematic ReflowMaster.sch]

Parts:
1: RD; CHIPLED_0805_NOOUTLINE
2: YEL; CHIPLED_0805_NOOUTLINE
13: GR; CHIPLED_0805_NOOUTLINE
B1, B2, B3, B4: MOMENTARY-SWITCH-SPST-PTH-RIGHT-ANGLE-KIT; TACTILE_SWITCH_PTH_RIGHT_ANGLE_KIT
BUZZ: CONN_02; 1X02
C1, C14: 1uF; 0805-NO
C2, C4: 12pF; 0805-NO
C3, C7: 0.1uF; 0805-NO
C5: 10nF; 0805-NO
C6, C8: 10µF; 0805-NO
D1: MBR120; SOD-123
FAN: CONN_02; 1X02
J1: CONN_041X04_NO_SILK; 1X04_NO_SILK
J2: USB_MICRO-B_FEMALE-SMT; USB-B-MICRO-SMD
K-TYPE: CONN_02; 1X02
LDO: AP2112K; SOT23-5
LOGO1: OSHW-LOGOS; OSHW-LOGO-S
MAX31855: GENERIC-SOIC8; SO08-UNIVERSAL
Q1: 600mA/40V; SOT23-3
R1: 100k; 0805-NO
R2: 430k; 0805-NO
R3, R8: 2K; 0805-NO
R4, R5, R6, R11: 10k; R0805
R7: 300R; 0805-NO
R9: 1K2; R0805
RELAY: CONN_02; 1X02
SAMD21: ATSAMD21G-A; TQFP-48
SW1: SPST_TACT-KMR2; KMR2
SWITCH: CONN_02; 1X02
TFT: CONN_14NO_SILK; 1X14_NO_SILK
X2: 32.768; XTAL3215

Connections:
!RESET: SAMD21.40 (!RESET!), SW1.1, SW1.3 (P1)
+3V3: B1.1, B2.1, B3.1, B4.1, C3.2, C7.1, C8.1, LDO.5 (OUT), MAX31855.4, SAMD21.6 (VDDANA), SAMD21.17 (VDDIO), SAMD21.36 (VDDIO), SAMD21.44 (VDDIN), TFT.8
A0: B1.2, R11.2, SAMD21.3 (PA02(AIN0/DAC))
A1: B2.2, R4.2, SAMD21.7 (PB08(AIN2/SER4:0/TC4:0))
A2: B3.2, R5.2, SAMD21.8 (PB09(AIN3/SER4:1/TC4:1))
A3: B4.2, R6.2, SAMD21.9 (PA04(AIN4/REFB/SER0:0/TC0:0))
A4: BUZZ.1, SAMD21.10 (PA05(AIN5/SER0:1/TC0:1))
A5: R9.2, SAMD21.47 (PB02(AIN10/SER5:0))
AREF: C14.1, SAMD21.4 (PA03(AIN1/REFA))
BASE: Q1.1 (B), R9.1
D0: SAMD21.16 (PA11(AIN19/SER0:3+)), TFT.5
D1: SAMD21.15 (PA10(AIN18/SER0:2+)), TFT.4
D2: SAMD21.23 (PA14(XIN/SER2:2+))
D3: SAMD21.14 (PA09(I2C/AIN17/SER0:1+)), TFT.3
D4: SAMD21.13 (PA08(I2C/AIN16/SER0:0+))
D5: R8.1, RELAY.2, SAMD21.24 (PA15(XOUT/SER2:3+))
D6: J1.4, SAMD21.29 (PA20(SER5:2+))
D7: J1.3, SAMD21.30 (PA21(SER5:3+))
D8: SAMD21.11 (PA06(AIN6/SER0:2/TC1:0))
D9: SAMD21.12 (PA07(AIN7/SER0:3/TC1:1))
D10: MAX31855.6, SAMD21.27 (PA18(SER1:2+))
D11: MAX31855.7, SAMD21.25 (PA16(I2C/SER1:0+))
D12: MAX31855.5, SAMD21.28 (PA19(SER1:3+))
D13: R7.1, SAMD21.26 (PA17(I2C/SER1:1+))
D+: J2.D+, SAMD21.34 (PA25(SER3:3+))
D-: J2.D-, SAMD21.33 (PA24(SER3:2+))
EN: LDO.3 (EN), R1.2
FAN: D1.A, FAN.2, Q1.3 (C)
GND: 1.C, 2.C, 13.C, BUZZ.2, C1.2, C2.2, C3.1, C4.2, C6.2, C7.2, C8.2, C14.2, J2.GND, J2.SHIELD1 (SHIELD), J2.SHIELD2 (SHIELD), J2.SHIELD3 (SHIELD), LDO.2 (GND), MAX31855.1, Q1.2 (E), R2.2, R4.1, R5.1, R6.1, R11.1, RELAY.1, SAMD21.5 (GNDANA), SAMD21.18 (GND), SAMD21.35 (GND), SAMD21.42 (GND), SW1.2 (S), SW1.4 (S1), TFT.2
MISO: SAMD21.21 (PA12(I2C/SER2:0+)), TFT.9
MOSI: SAMD21.19 (PB10(SER4:2+)), TFT.6
unnamed: 1.A, R3.2
unnamed: 13.A, R7.2
unnamed: 2.A, R8.2
unnamed: C4.1, SAMD21.1 (PA00(XIN32/SER1:0/TC2:0)), X2.P$2
unnamed: C2.1, SAMD21.2 (PA01(XOUT32/SER1:1/TC2:1)), X2.P$1
SCK: SAMD21.20 (PB11(SER4:3+)), TFT.7
SCL: J1.1, SAMD21.32 (PA23(I2C/SER3:0+))
SDA: J1.2, SAMD21.31 (PA22(I2C/SER3:0+))
SWCLK: SAMD21.45 (PA30(SWCLK/SER1:2+))
SWDIO: SAMD21.46 (PA31(SWDIO/SER1:3+))
T+: C5.1, K-TYPE.2, MAX31855.3
T-: C5.2, K-TYPE.1, MAX31855.2
VBUS: C6.1, D1.C, FAN.1, J2.VBUS, LDO.1 (IN), R1.1, R2.1, R3.1, SWITCH.1, SWITCH.2, TFT.1
VDDCORE: C1.1, SAMD21.43 (VDDCORE)

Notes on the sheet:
POWER AND FILTERING
RESET
GENERAL IO
RED LED

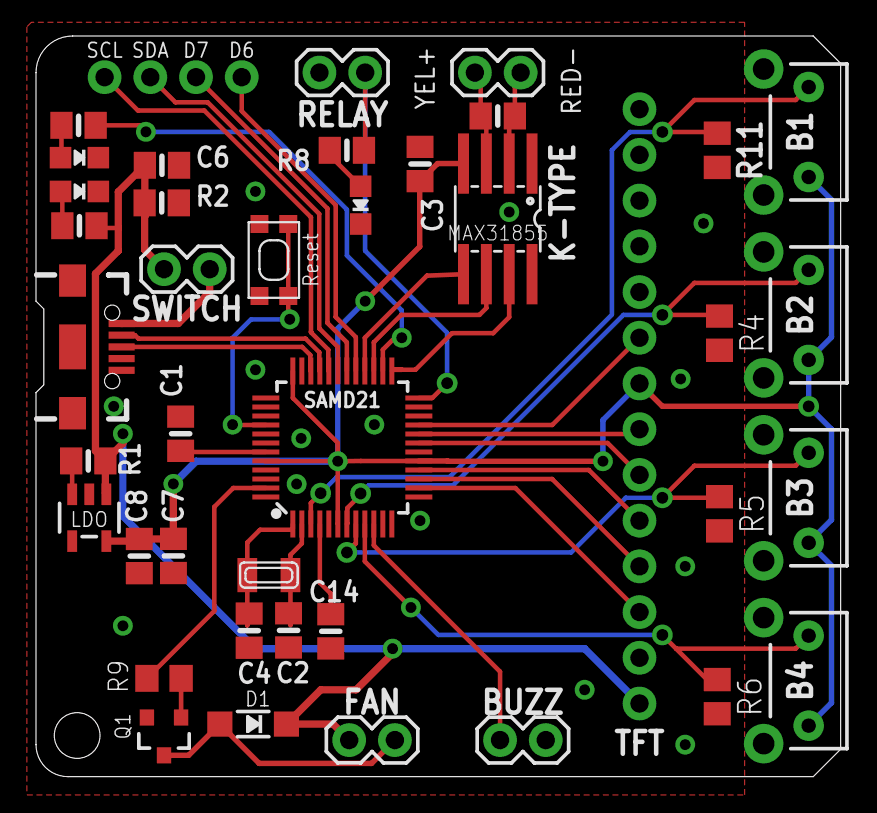
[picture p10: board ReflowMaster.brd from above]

Board: 2 copper layers, 44.7 x 41.1 mm, 42 parts (1 on the bottom side), 39 nets.

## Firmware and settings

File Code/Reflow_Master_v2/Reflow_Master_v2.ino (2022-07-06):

/*
  ---------------------------------------------------------------------------
  Reflow Master Control - v2.05 - 07/07/2022

  AUTHOR/LICENSE:
  Created by Seon Rozenblum - seon@unexpectedmaker.com
  Copyright 2016 License: GNU GPL v3 http://www.gnu.org/licenses/gpl-3.0.html

  LINKS:
  Project home: github.com/unexpectedmaker/reflowmaster
  Blog: unexpectedmaker.comYes, 

  PURPOSE:
  This controller is the software that runs on the Reflow Master toaster oven controller made by Unexpected Maker

  HISTORY:
  01/08/2018 v1.0   - Initial release.
  13/08/2018 v1.01  - Settings UI button now change to show SELECT or CHANGE depending on what is selected
  27/08/2018 v1.02  - Added tangents to the curve for ESP32 support, Improved graph curves, fixed some UI glitches, made end graph time value be the end profile time
  28/08/2018 v1.03  - Added some graph smoothing
  20/05/2019 v1.04  - Increased max curve to support profiles up to 8mins
                    - Added fan on time after reflow for cooldown settings
                    - Added extra profile for Ju Feng Medium temp paste
  07/09/2019 v1.05  - Fixed some bugs, Thanks Tablatronix!
  16/09/2019 v1.06  - Fixed probe offset temp not changing in settings
  02/07/2020 v1.07  - Cleaned up some Fan control and tracking code
                    - Cleaned up some debug messages
  13/07/2020 v1.08  - Fixed bug in DEBUG mode
  17/07/2020 v1.09  - Added TC error display in menu if an error is found
                    - Prevent starting reflow or oven check if there is a TC error
                    - Code refactor for easier reading? maybe?
  19/12/2020 v2.00  - Added baking mode
                    - Lots of code cleanup and simplification
                    - Included the more obscure libraries inside the sketch
  20/12/2020 v2.01  - Forgot to hookup minBakeTemp, minBakeTime, maxBakeTemp, maxBakeTemp variables to buttons
                    - Increased max bake time to 3 hours
                    - Added long press for Bake Time & Temp to quickly change values, clamped at max, so it won't loop
                    - Oven was not turned off correctly after the bake ended
  20/12/2020 v2.02  - Prevent going into the Bake menu when there is a thermocouple error
                    - Set FAN to Off by default
                    - Fixed some incorrect comments 
                    - Made TC error more visible
  21/12/2020 v2.02  - Fixed UI glitch in main menu with TC error display
  12/05/2021 v2.03  - Increased BAKE max Temperature to 150deg C
  31/10/2021 v2.04  - Some code cleanup and optimisations and merge of fixes from @dmadison
  07/07/2022 v2.05  - Fixed a compiler error with spline lib using latest Adafruit SAMD board definitions (>1.6.6)
  -----------------------------------------------------------------------------------------------------------------
*/

/*
   NOTE: This is a work in progress...
*/

#include <SPI.h>
#include "spline.h"
#include "Adafruit_GFX.h" // Add from Library Manager
#include "Adafruit_ILI9341.h" // Add from Library Manager
#include "MAX31855.h"
#include "OneButton.h" // Add from Library Manager
#include "ReflowMasterProfile.h"
#include "FlashStorage.h"

// used to obtain the size of an array of any type
#define ELEMENTS(x)   (sizeof(x) / sizeof(x[0]))

// used to show or hide serial debug output
#define DEBUG

// TFT SPI pins
#define TFT_DC 0
#define TFT_CS 3
#define TFT_RESET 1

// MAX 31855 Pins
#define MAXDO   11
#define MAXCS   10
#define MAXCLK  12

#define BUTTON0 A0 // menu buttons
#define BUTTON1 A1 // menu buttons
#define BUTTON2 A2 // menu buttons
#define BUTTON3 A3 // menu buttons

#define BUZZER A4  // buzzer
#define RELAY 5    // relay control
#define FAN A5     // fan control

// Just a bunch of re-defined colours
#define BLUE      0x001F
#define TEAL      0x0438
#define GREEN     0x07E0
#define CYAN      0x07FF
#define RED       0xF800
#define MAGENTA   0xF81F
#define YELLOW    0xFFE0
#define ORANGE    0xFC00
#define PINK      0xF81F
#define PURPLE    0x8010
#define GREY      0xC618
#define WHITE     0xFFFF
#define BLACK     0x0000
#define DKBLUE    0x000D
#define DKTEAL    0x020C
#define DKGREEN   0x03E0
#define DKCYAN    0x03EF
#define DKRED     0x6000
#define DKMAGENTA 0x8008
#define DKYELLOW  0x8400
#define DKORANGE  0x8200
#define DKPINK    0x9009
#define DKPURPLE  0x4010
#define DKGREY    0x4A49

// Save data struct
typedef struct {
  boolean valid = false;
  boolean useFan = false;
  int fanTimeAfterReflow = 60;
  byte paste = 0;
  float power = 1;
  int lookAhead = 6;
  int lookAheadWarm = 1;
  int tempOffset = 0;
  long bakeTime = 1200; // 20 mins
  float bakeTemp = 45; // Degrees C
  int bakeTempGap = 3; // Aim for the desired temp minus this value to compensate for overrun
  bool startFullBlast = false;
  bool beep = true;
} Settings;

// UI and runtime states
enum states {
  BOOT = 0,
  WARMUP = 1,
  REFLOW = 2,
  FINISHED = 3,
  MENU = 10,
  SETTINGS = 11,
  SETTINGS_PASTE = 12,
  SETTINGS_RESET = 13,
  OVENCHECK = 15,
  OVENCHECK_START = 16,
  BAKE_MENU = 20,
  BAKE = 21,
  BAKE_DONE = 22,
  ABORT = 99
} state;

const String ver = "2.05";
bool newSettings = false;

// TC variables
unsigned long nextTempRead;
unsigned long nextTempAvgRead;
int avgReadCount = 0;

unsigned long keepFanOnTime = 0;

double timeX = 0;
double tempOffset = 60;

// Bake variables
long currentBakeTime = 0; // Used to countdown the bake time
byte currentBakeTimeCounter = 0;
int lastTempDirection = 0;
long minBakeTime = 600; // 10 mins in seconds
long maxBakeTime = 10800; // 3 hours in seconds
float minBakeTemp = 45; // 45 Degrees C
float maxBakeTemp = 150; // 100 Degrees C

// Current index in the settings screen
int settings_pointer = 0;

// Initialise an array to hold 5 profiles
// Increase this array if you plan to add more
ReflowGraph solderPaste[5];
// Index into the current profile

int currentGraphIndex = 0;

// Calibration data - currently diabled in this version
int calibrationState = 0;
long calibrationSeconds = 0;
long calibrationStatsUp = 0;
long calibrationStatsDown = 300;
bool calibrationUpMatch = false;
bool calibrationDownMatch = false;
float calibrationDropVal = 0;
float calibrationRiseVal = 0;

// Runtime reflow variables
int tcError = 0;
bool tcWasError = false;
bool tcWasGood = true;
float currentDuty = 0;
float currentTemp = 0;
float cachedCurrentTemp = 0;
float currentTempAvg = 0;
float lastTemp = -1;
float currentDetla = 0;
unsigned int currentPlotColor = GREEN;
bool isCuttoff = false;
bool isFanOn = false;
float lastWantedTemp = -1;
int buzzerCount = 5;

// Graph Size for UI
int graphRangeMin_X = 0;
int graphRangeMin_Y = 30;
int graphRangeMax_X = -1;
int graphRangeMax_Y = 165;
int graphRangeStep_X = 30;
int graphRangeStep_Y = 15;

// Create a spline reference for converting profile values to a spline for the graph
Spline baseCurve;

// Initialise the TFT screen
Adafruit_ILI9341 tft = Adafruit_ILI9341(TFT_CS, TFT_DC, TFT_RESET);

// Initialise the MAX31855 IC for thermocouple tempterature reading
MAX31855 tc(MAXCLK, MAXCS, MAXDO);

// Initialise the buttons using OneButton library
OneButton button0(BUTTON0, false);
OneButton button1(BUTTON1, false);
OneButton button2(BUTTON2, false);
OneButton button3(BUTTON3, false);

// UI button positions and sizes
int buttonPosY[] = { 19, 74, 129, 184 };
int buttonHeight = 16;
int buttonWidth = 4;

// Initiliase a reference for the settings file that we store in flash storage
Settings set;
// Initialise flash storage
FlashStorage(flash_store, Settings);

// This is where we initialise each of the profiles that will get loaded into the Reflkow Master
void LoadPaste()
{
  /*
    Each profile is initialised with the follow data:

        Paste name ( String )
        Paste type ( String )
        Paste Reflow Temperature ( int )
        Profile graph X values - time
        Profile graph Y values - temperature
        Length of the graph  ( int, how long if the graph array )
  */
  float baseGraphX[7] = { 1, 90, 180, 210, 240, 270, 300 }; // time
  float baseGraphY[7] = { 27, 90, 130, 138, 165, 138, 27 }; // value

  solderPaste[0] = ReflowGraph( "CHIPQUIK", "No-Clean Sn42/Bi57.6/Ag0.4", 138, baseGraphX, baseGraphY, ELEMENTS(baseGraphX) );

  float baseGraphX1[7] = { 1, 90, 180, 225, 240, 270, 300 }; // time
  float baseGraphY1[7] = { 25, 150, 175, 190, 210, 125, 50 }; // value

  solderPaste[1] = ReflowGraph( "CHEMTOOLS L", "No Clean 63CR218 Sn63/Pb37", 183, baseGraphX1, baseGraphY1, ELEMENTS(baseGraphX1) );

  float baseGraphX2[6] = { 1, 75, 130, 180, 210, 250 }; // time
  float baseGraphY2[6] = { 25, 150, 175, 210, 150, 50 }; // value

  solderPaste[2] = ReflowGraph( "CHEMTOOLS S", "No Clean 63CR218 Sn63/Pb37", 183, baseGraphX2, baseGraphY2, ELEMENTS(baseGraphX2) );

  float baseGraphX3[7] = { 1, 60, 120, 160, 210, 260, 310 }; // time
  float baseGraphY3[7] = { 25, 105, 150, 150, 220, 150, 20 }; // value

  solderPaste[3] = ReflowGraph( "DOC SOLDER", "No Clean Sn63/Pb36/Ag2", 187, baseGraphX3, baseGraphY3, ELEMENTS(baseGraphX3) );

  float baseGraphX4[6] = { 1, 90, 165, 225, 330, 360 }; // time
  float baseGraphY4[6] = { 25, 150, 175, 235, 100, 25 }; // value

  solderPaste[4] = ReflowGraph( "CHEMTOOLS SAC305 HD", "Sn96.5/Ag3.0/Cu0.5", 225, baseGraphX4, baseGraphY4, ELEMENTS(baseGraphX4) );

  //TODO: Think of a better way to initalise these baseGraph arrays to not need unique array creation
}

// Obtain the temp value of the current profile at time X
int GetGraphValue( int x )
{
  return ( CurrentGraph().reflowTemp[x] );
}

int GetGraphTime( int x )
{
  return ( CurrentGraph().reflowTime[x] );
}

// Obtain the current profile
ReflowGraph CurrentGraph()
{
  return solderPaste[ currentGraphIndex ];
}

// Set the current profile via the array index
void SetCurrentGraph( int index )
{
  currentGraphIndex = index;
  graphRangeMax_X = CurrentGraph().MaxTime();
  graphRangeMax_Y = CurrentGraph().MaxTempValue() + 5; // extra padding
  graphRangeMin_Y = CurrentGraph().MinTempValue();

  debug_print("Setting Paste: ");
  debug_println( CurrentGraph().n );
  debug_println( CurrentGraph().t );

  // Initialise the spline for the profile to allow for smooth graph display on UI
  timeX = 0;
  baseCurve.setPoints(CurrentGraph().reflowTime, CurrentGraph().reflowTemp, CurrentGraph().reflowTangents, CurrentGraph().len);
  baseCurve.setDegree( Hermite );

  // Re-interpolate data based on spline
  for ( int ii = 0; ii <= graphRangeMax_X; ii += 1 )
  {
    solderPaste[ currentGraphIndex ].wantedCurve[ii] = baseCurve.value(ii);
  }

  // calculate the biggest graph movement delta
  float lastWanted = -1;
  for ( int i = 0; i < solderPaste[ currentGraphIndex ].offTime; i++ )
  {
    float wantedTemp = solderPaste[ currentGraphIndex ].wantedCurve[ i ];

    if ( lastWanted > -1 )
    {
      float wantedDiff = (wantedTemp - lastWanted );

      if ( wantedDiff > solderPaste[ currentGraphIndex ].maxWantedDelta )
        solderPaste[ currentGraphIndex ].maxWantedDelta = wantedDiff;
    }
    lastWanted  = wantedTemp;
  }
}

void setup()
{
  // Setup all GPIO
  pinMode( BUZZER, OUTPUT );
  pinMode( RELAY, OUTPUT );
  pinMode( FAN, OUTPUT );
  pinMode( BUTTON0, INPUT );
  pinMode( BUTTON1, INPUT );
  pinMode( BUTTON2, INPUT );
  pinMode( BUTTON3, INPUT );

  // Turn of Green Debug LED
  pinMode( 13, INPUT );

  // Turn off the SSR - duty cycle of 0
  SetRelayFrequency( 0 );

#ifdef DEBUG
  Serial.begin(115200);
#endif

  // just wait a bit before we try to load settings from FLASH
  delay(500);

  // load settings from FLASH
  set = flash_store.read();

  // If no settings were loaded, initialise data and save
  if ( !set.valid )
  {
    SetDefaults();
    newSettings = true;
    flash_store.write(set);
  }

  // Attatch button IO for OneButton
  button0.attachClick(button0Press);
  button1.attachClick(button1Press);
  button2.attachClick(button2Press);
  button3.attachClick(button3Press);

  // New long press buttons for changing bake time and temp values
  button2.attachLongPressStart(button2LongPressStart);
  button2.attachDuringLongPress(button2LongPress);
  button3.attachLongPressStart(button3LongPressStart);
  button3.attachDuringLongPress(button3LongPress);

  debug_println("TFT Begin...");

  // Start up the TFT and show the boot screen
  tft.begin(32000000);
  BootScreen();
  BuzzerStart();

  delay(200);

  // Start up the MAX31855
  debug_println("Thermocouple Begin...");
  tc.begin();

  // delay for initial temp probe read to be garbage
  delay(500);

  // Load up the profiles
  LoadPaste();
  // Set the current profile based on last selected
  SetCurrentGraph( set.paste );

  delay(500);

  // Show the main menu
  ShowMenu();
}

// Helper method to display the temperature on the TFT
void DisplayTemp( bool center = false )
{
  if ( center )
  {
    tft.setTextColor( YELLOW, BLACK );
    tft.setTextSize(5);
    println_Center( tft, "  " + String( round( currentTemp ) ) + "c  ", tft.width() / 2, ( tft.height() / 2 ) + 10 );
  }
  else
  {
    if ( round( currentTemp ) != round( cachedCurrentTemp ) )
    {
      // display the previous temp in black to clear it
      tft.setTextColor( BLACK, BLACK );
      tft.setTextSize(6);
      tft.setCursor( 20,  ( tft.height() / 2 ) - 25 );
      tft.println( String( round( cachedCurrentTemp ) ) + "c" );

      // display the new temp in green
      tft.setTextColor( GREEN, BLACK );
      tft.setCursor( 20,  ( tft.height() / 2 ) - 25 );
      tft.println( String( round( currentTemp ) ) + "c" );

      // cache the current temp
      cachedCurrentTemp = currentTemp;
    }
  }
}

void loop()
{
  // Used by OneButton to poll for button inputs
  button0.tick();
  button1.tick();
  button2.tick();
  button3.tick();

  // Current activity state machine
  if ( state == BOOT ) // BOOT
  {
    return;
  }
  else if ( state == WARMUP ) // WARMUP - We sit here until the probe reaches the starting temp for the profile
  {
    if ( nextTempRead < millis() ) // we only read the probe every second
    {
      nextTempRead = millis() + 1000;

      ReadCurrentTemp();
      MatchTemp();

      if ( currentTemp >= GetGraphValue(0) )
      {
        // We have reached the starting temp for the profile, so lets start baking our boards!
        lastTemp = currentTemp;
        avgReadCount = 0;
        currentTempAvg = 0;

        StartReflow();
      }
      else if ( currentTemp > 0 )
      {
        // Show the current probe temp so we can watch as it reaches the minimum starting value
        DisplayTemp( true );
      }
    }
    return;
  }
  else if ( state == FINISHED ) // FINISHED
  {
    // do we keep the fan on after reflow finishes to help cooldown?
    KeepFanOnCheck();
    return;
  }
  else if ( state == SETTINGS || state == SETTINGS_PASTE || state == SETTINGS_RESET ) // SETTINGS
  {
    // Currently not used
    return;
  }
  else if ( state == MENU ) // MENU
  {
    if ( nextTempRead < millis() )
    {
      nextTempRead = millis() + 1000;

      // We show the current probe temp in the men screen just for info
      ReadCurrentTemp();

      if ( tcError > 0 )
      {
        // Clear TC Temp background if there was one!
        if ( tcWasGood )
        {
          tcWasGood = false;
          tft.setTextColor( BLACK, BLACK );
          tft.setTextSize(6);
          tft.setCursor( 20,  ( tft.height() / 2 ) - 25 );
          tft.println( String( round( cachedCurrentTemp ) ) + "c" );

          tft.fillRect( 5, tft.height() / 2 - 20, 180, 31, RED );
        }
        tcWasError = true;
        tft.setTextColor( WHITE, RED );
        tft.setTextSize(3);        
        tft.setCursor( 10, ( tft.height() / 2 ) - 15 );
        tft.println( "TC ERR #" + String( tcError ) );
      }
      else if ( currentTemp > 0 )
      {
        // Clear error background if there was one!
        if ( tcWasError )
        {
          cachedCurrentTemp = 0;
          tcWasError = false;
          tft.fillRect( 0, tft.height() / 2 - 20, 200, 32, BLACK );
        }
        tcWasGood = true;
        DisplayTemp();
      }
    }

    // do we keep the fan on after reflow finishes to help cooldown?
    KeepFanOnCheck();
    return;
  }
  else if ( state == BAKE_MENU || state == BAKE_DONE )
  {
    // do nothing in these states
  }
  else if ( state == BAKE )
  {
    if ( currentBakeTime > 0 )
    {
      if ( nextTempAvgRead < millis() )
      {
        nextTempAvgRead = millis() + 100;
        ReadCurrentTempAvg();
      }

      if ( nextTempRead < millis() )
      {
        nextTempRead = millis() + 1000;

        // Set the temp from the average
        currentTemp = ( currentTempAvg / avgReadCount );
        // clear the variables for next run
        avgReadCount = 0;
        currentTempAvg = 0;

        // Control the SSR
        MatchTemp_Bake();

        if ( currentTemp > 0 )
          currentBakeTime--;
      }

      UpdateBake();
    }
    else
    {
      BakeDone();
    }
  }
  else if ( state == OVENCHECK )
  {
    // Currently not used
    return;
  }
  else if ( state == OVENCHECK_START ) // calibration - not currently used
  {
    if ( nextTempRead < millis() )
    {
      nextTempRead = millis() + 1000;

      ReadCurrentTemp();

      MatchCalibrationTemp();

      if ( calibrationState < 2 )
      {
        tft.setTextColor( CYAN, BLACK );
        tft.setTextSize(2);

        if ( calibrationState == 0 )
        {
          if ( currentTemp < GetGraphValue(0) )
            println_Center( tft, "WARMING UP", tft.width() / 2, ( tft.height() / 2 ) - 15 );
          else
            println_Center( tft, "HEAT UP SPEED", tft.width() / 2, ( tft.height() / 2 ) - 15 );

          println_Center( tft, "TARGET " + String( GetGraphValue(1) ) + "c in " + String( GetGraphTime(1) ) + "s", tft.width() / 2, ( tft.height() - 18 ) );
        }
        else if ( calibrationState == 1 )
        {
          println_Center( tft, "COOL DOWN LEVEL", tft.width() / 2, ( tft.height() / 2 ) - 15 );
          tft.fillRect( 0, tft.height() - 30, tft.width(), 30, BLACK );
        }

        // only show the timer when we have hit the profile starting temp
        if (currentTemp >= GetGraphValue(0) )
        {
          // adjust the timer colour based on good or bad values
          if ( calibrationState == 0 )
          {
            if ( calibrationSeconds <= GetGraphTime(1) )
              tft.setTextColor( WHITE, BLACK );
            else
              tft.setTextColor( ORANGE, BLACK );
          }
          else
          {
            tft.setTextColor( WHITE, BLACK );
          }

          tft.setTextSize(4);
          println_Center( tft, " " + String( calibrationSeconds ) + " secs ", tft.width() / 2, ( tft.height() / 2 ) + 20 );
        }
        tft.setTextSize(5);
        tft.setTextColor( YELLOW, BLACK );
        println_Center( tft, " " + String( round( currentTemp ) ) + "c ", tft.width() / 2, ( tft.height() / 2 ) + 65 );


      }
      else if ( calibrationState == 2 )
      {
        calibrationState = 3;

        tft.setTextColor( GREEN, BLACK );
        tft.setTextSize(2);
        tft.fillRect( 0, (tft.height() / 2 ) - 45, tft.width(), (tft.height() / 2 ) + 45, BLACK );
        println_Center( tft, "RESULTS!", tft.width() / 2, ( tft.height() / 2 ) - 45 );

        tft.setTextColor( WHITE, BLACK );
        tft.setCursor( 20, ( tft.height() / 2 ) - 10 );
        tft.print( "RISE " );
        if ( calibrationUpMatch )
        {
          tft.setTextColor( GREEN, BLACK );
          tft.print( "PASS" );
        }
        else
        {
          tft.setTextColor( ORANGE, BLACK );
          tft.print( "FAIL " );
          tft.setTextColor( WHITE, BLACK );
          tft.print( "REACHED " + String( round(calibrationRiseVal * 100) ) + "%") ;
        }

        tft.setTextColor( WHITE, BLACK );
        tft.setCursor( 20, ( tft.height() / 2 ) + 20 );
        tft.print( "DROP " );
        if ( calibrationDownMatch )
        {
          tft.setTextColor( GREEN, BLACK );
          tft.print( "PASS" );
          tft.setTextColor( WHITE, BLACK );
          tft.print( "DROPPED " + String( round(calibrationDropVal * 100) ) + "%") ;
        }
        else
        {
          tft.setTextColor( ORANGE, BLACK );
          tft.print( "FAIL " );
          tft.setTextColor( WHITE, BLACK );
          tft.print( "DROPPED " + String( round(calibrationDropVal * 100) ) + "%") ;

          tft.setTextColor( WHITE, BLACK );
          tft.setCursor( 20, ( tft.height() / 2 ) + 40 );
          tft.print( "RECOMMEND ADDING FAN") ;
        }
      }
    }
  }
  else // state is REFLOW
  {
    if ( nextTempAvgRead < millis() )
    {
      nextTempAvgRead = millis() + 100;
      ReadCurrentTempAvg();
    }
    if ( nextTempRead < millis() )
    {
      nextTempRead = millis() + 1000;

      // Set the temp from the average
      currentTemp = ( currentTempAvg / avgReadCount );
      // clear the variables for next run
      avgReadCount = 0;
      currentTempAvg = 0;

      // Control the SSR
      MatchTemp();

      if ( currentTemp > 0 )
      {
        timeX++;

        if ( timeX > CurrentGraph().completeTime )
        {
          EndReflow();
        }
        else
        {
          Graph(tft, timeX, currentTemp, 30, 220, 270, 180 );

          if ( timeX < CurrentGraph().fanTime )
          {
            float wantedTemp = CurrentGraph().wantedCurve[ (int)timeX ];
            DrawHeading( String( round( currentTemp ) ) + "/" + String( (int)wantedTemp ) + "c", currentPlotColor, BLACK );
          }
        }
      }
    }
  }
}
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

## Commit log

2018-08-10 Added STL files for the 3D printed case
    [Case_Back.stl, Case_Front.stl]
2018-08-11 Added PDF of the schematic and BOM parts list
2018-08-12 Upped code to v1.01 Settings UI button now change to show SELECT or CHANGE depending on what is selected
2018-08-27 Added tangents to the curve for ESP32 support Improved graph curves Fixed some UI glitches Made end graph time value be the end profile time
    [ReflowMasterProfile.h]
2018-08-28 Moved to averaged temp reading to help reduce probe noise Temp is now read 10 times per second and averaged.
2018-08-31 Added new 8.5mm header variant and updated 5mm variant for the front of the Reflow Master cases Added info about the files
    [Case_Front.stl, Case_Front_5mm_Header.stl, Case_Front_8.5mm_Header.stl]
2019-02-08 Added STL for exhaust fan
    [Fan_Exhaust.stl]
2019-02-08 Added notes in readme for the STL file for the air exhaust fan
2019-05-28 Updated BOM + Schematic pDF + Eagle files with missing part types Changed 12.5pF caps for XTAL to 12pF caps.
    [ReflowMaster.brd, ReflowMaster.sch]
2019-07-07 07/09/2019 v1.05 - Fixed some bugs, Thanks Tablatronix!
    20/05/2019 v1.04
    - Increased max curve array size to support profiles up to 8mins
    - Added fan on time after reflow for cooldown settings to keep the fan on for X seconds to help cool the oven down
    - Added extra profile for Ju Feng Medium temp paste - 183deg - No Clean 63CR218 Sn64/Bi35/AG1
    [ReflowMasterProfile.h]
2019-07-26 Updated the STL for the front of the case
    [Case_Front_5mm_Header.stl, Case_Front_8.5mm_Header.stl]
2019-09-16 Fixed probe temp offset not being changeable in settings Added version history to readme
2020-07-01 Updated all of the STL files for the different case versions
    [Case_Back.stl, Case_Front_8.5mm_Header.stl, Reflow_Master_Back_V2.stl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]
2020-07-02 Updated to latest Reflow Master Arduino code
    02/07/2020 v1.07
    - Cleaned up some Fan control and tracking code
    - Cleaned up some debug messages
2020-12-19 Added version 2.0.0 project code with new bake feature!
    [ReflowMaster_BOM.csv]
2020-12-19 Updated to v2.01 New - Increased max bake time to 3 hours - Added long press for Bake Time & Temp to quickly change values, clamped at max, so it won't loop Fixes - Forgot to hookup minBakeTemp, minB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
    [ReflowMasterProfile.h, Reflow_Master_v2.ino]
2020-12-20 Version 2.02 - Prevent going into the bake menu when there is a TC error - Set FAN to Off by default in settings - Fixed some incorrect comments - Made TC error more visible on menu screen
    [Reflow_Master_v2.ino]
2020-12-21 Fixed UI glitch in main menu with TC error display Keeping version at 2.02
    [Reflow_Master_v2.ino]
2021-05-20 Make millis() tracking variables unsigned
2021-05-20 Fix signed vs unsigned comparison errors
    size_t for element comparison, and signed int for the settings_pointer (so decrementing can check for -1 without rollover)
    [ReflowMasterProfile.h, Reflow_Master_v2.ino]
2021-05-20 Remove string2char helper
    Unless I'm missing something I believe this is ill-formed? The String is passed by copy and this returns a pointer to the underlying heap memory, so it's possible that the memory will get overwritten before the string is used.
    Instead we can just pass the c_str() directly, as the function doesn't care about const-ness. This eliminates the compiler warning that function may fail to return a pointer if the string is 0 length, and avoids potentially passing nullptr to the getTextBounds function.
    [Reflow_Master_v2.ino]
2021-10-31 Put tc.getInternal() back in after previous merge.
    Calling tc.getInternal() is required by the Max chip to do proper cold junction compensation at the time of reading the actual TC temperature.
2021-10-31 Fix compilation error and warning from 423e6ef
    The previous commit is missing a semicolon on line 812 which breaks compilation.
    While the getInternal() function call is apparently needed this removes the variable allocations which are not (and are generating a warning).
    [Reflow_Master_v2.ino]
2022-07-06 Fixed spline error using latest board manager version for Adafruit SAMD boards (>1.6.6) Updated version to 2.0.5
    [Reflow_Master_v2.ino]

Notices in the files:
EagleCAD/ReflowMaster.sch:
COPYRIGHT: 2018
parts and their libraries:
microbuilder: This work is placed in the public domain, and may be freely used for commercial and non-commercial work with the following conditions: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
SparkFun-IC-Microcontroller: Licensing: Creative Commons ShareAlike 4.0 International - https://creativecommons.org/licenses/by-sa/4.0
